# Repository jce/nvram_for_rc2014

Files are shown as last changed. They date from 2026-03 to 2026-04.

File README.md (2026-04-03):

## NVRAM module for the RC2014.
Pages the lower 32K out when the ROM module is present. Does not forget its content even when powered off. Therefore can be used as program storage in addition to remanent data.

Data and address traces are mostly connected in sequence. This means the ordering is slightly jumbled. But writing and reading back memory content makes the same transformations so this is functionally fine.

PCB 1.1 front
PCB 1.1 back
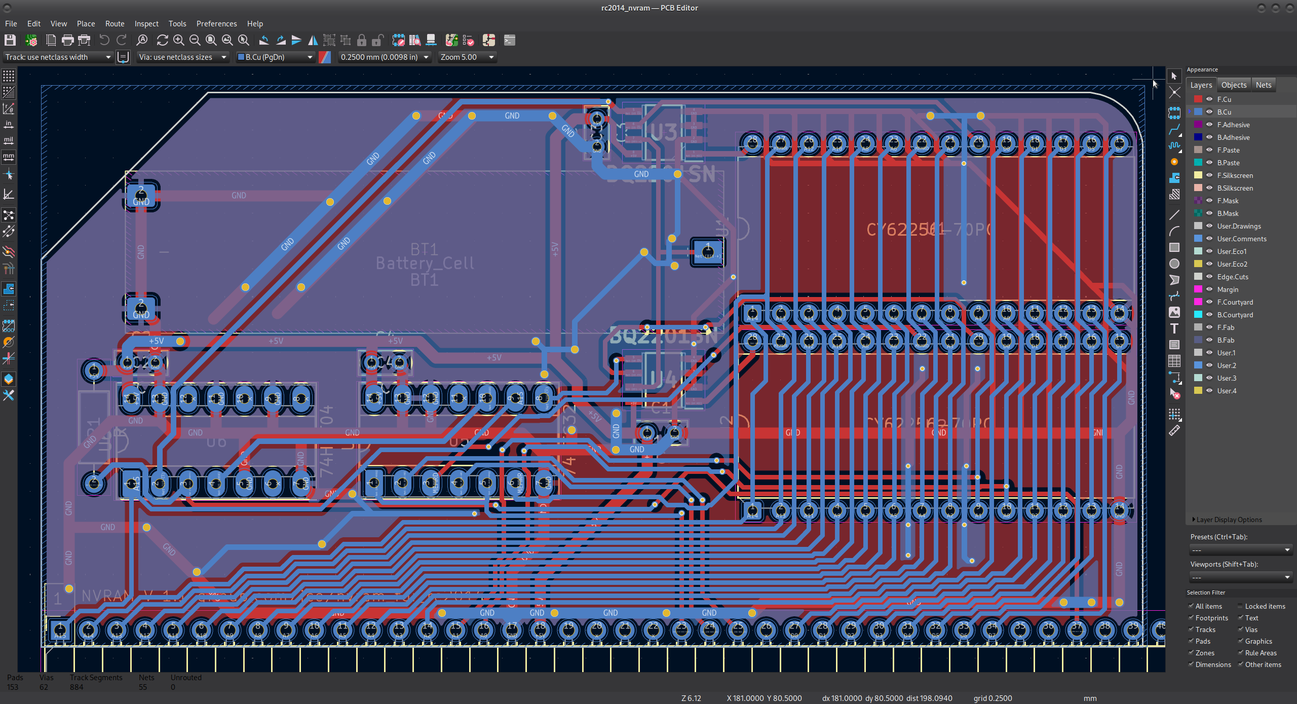
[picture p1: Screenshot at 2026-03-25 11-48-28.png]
PCB 1.1 kicad


Errata for building pcb V 1.1 (actual, and in picture):
- Typo in ic name: 74HTC32 should be 74HCT32
- Resistor and capacitor value not in drawing / on silkscreen
- Hole in RC2014 standard is missing
- "Page" pin is on SPARE1, instead of the second pinheader row, which is absent.

Errata for building of the V 1.0 proto:
- 74LS32 should be 74HTC32
- RC2014bus pin1 is not indicated
- IC types are not on silkscreen
- Pull up resistor value is missing: 10K
- Partlist missing
- Ground issues. Bridge some ground planes if you want to use this proto!
- Top memory is the bottom ic, ic's are reversed.

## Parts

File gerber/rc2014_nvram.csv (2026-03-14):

Id | Designator | Footprint | Quantity | Designation | Supplier and ref
1 | U5 | DIP-14_W7.62mm_Socket_LongPads | 1 | 74HTC32
2 | U1,U2 | DIP-28_W15.24mm | 2 | CY62256-70PC
3 | R1 | R_Axial_DIN0207_L6.3mm_D2.5mm_P10.16mm_Horizontal | 1 | 10K
4 | U6 | DIP-14_W7.62mm_Socket_LongPads | 1 | 74HCT04
5 | Z80_BUS1 | PinHeader_1x40_P2.54mm_Horizontal | 1 | ~
6 | BT1 | ER14505 | 1 | Battery_Cell
7 | C3,C1,C4,C2 | C_Rect_L4.6mm_W2.0mm_P2.50mm_MKS02_FKP02 | 4 | C
8 | U3,U4 | SOIC127P600X175-8N | 2 | BQ2201SN

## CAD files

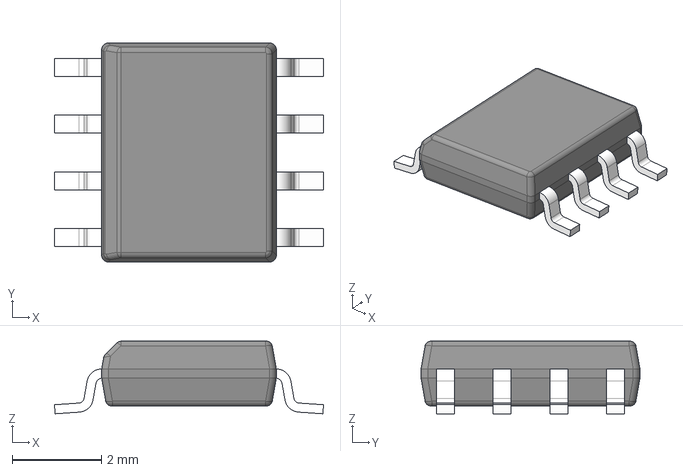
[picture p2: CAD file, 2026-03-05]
BQ2201SN-N/3D/BQ2201SN-N.stp
6.02 x 4.90 x 1.63 mm
BODY-SO
LEAD-D0008B x 8

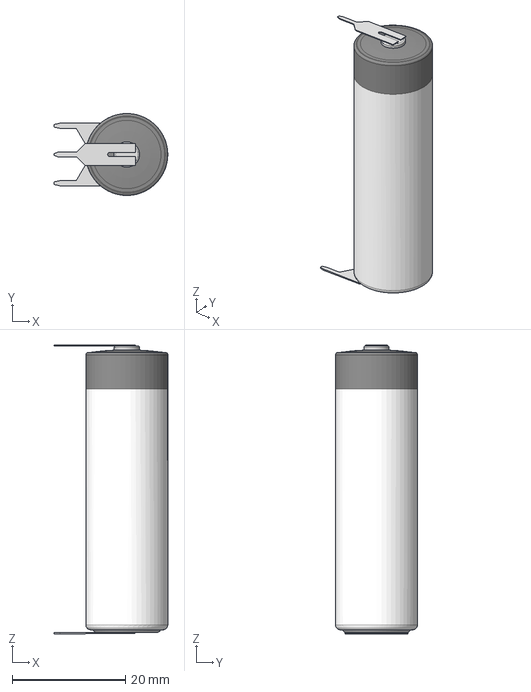
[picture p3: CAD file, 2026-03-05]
ER145053FP.stp
20.1 x 14.5 x 51.1 mm

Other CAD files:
BQ2201SN-N/Allegro/soic127p600x175-8n.psm
BQ2201SN-N/DEHDL/bq2201sn_n/chips/chips.prt

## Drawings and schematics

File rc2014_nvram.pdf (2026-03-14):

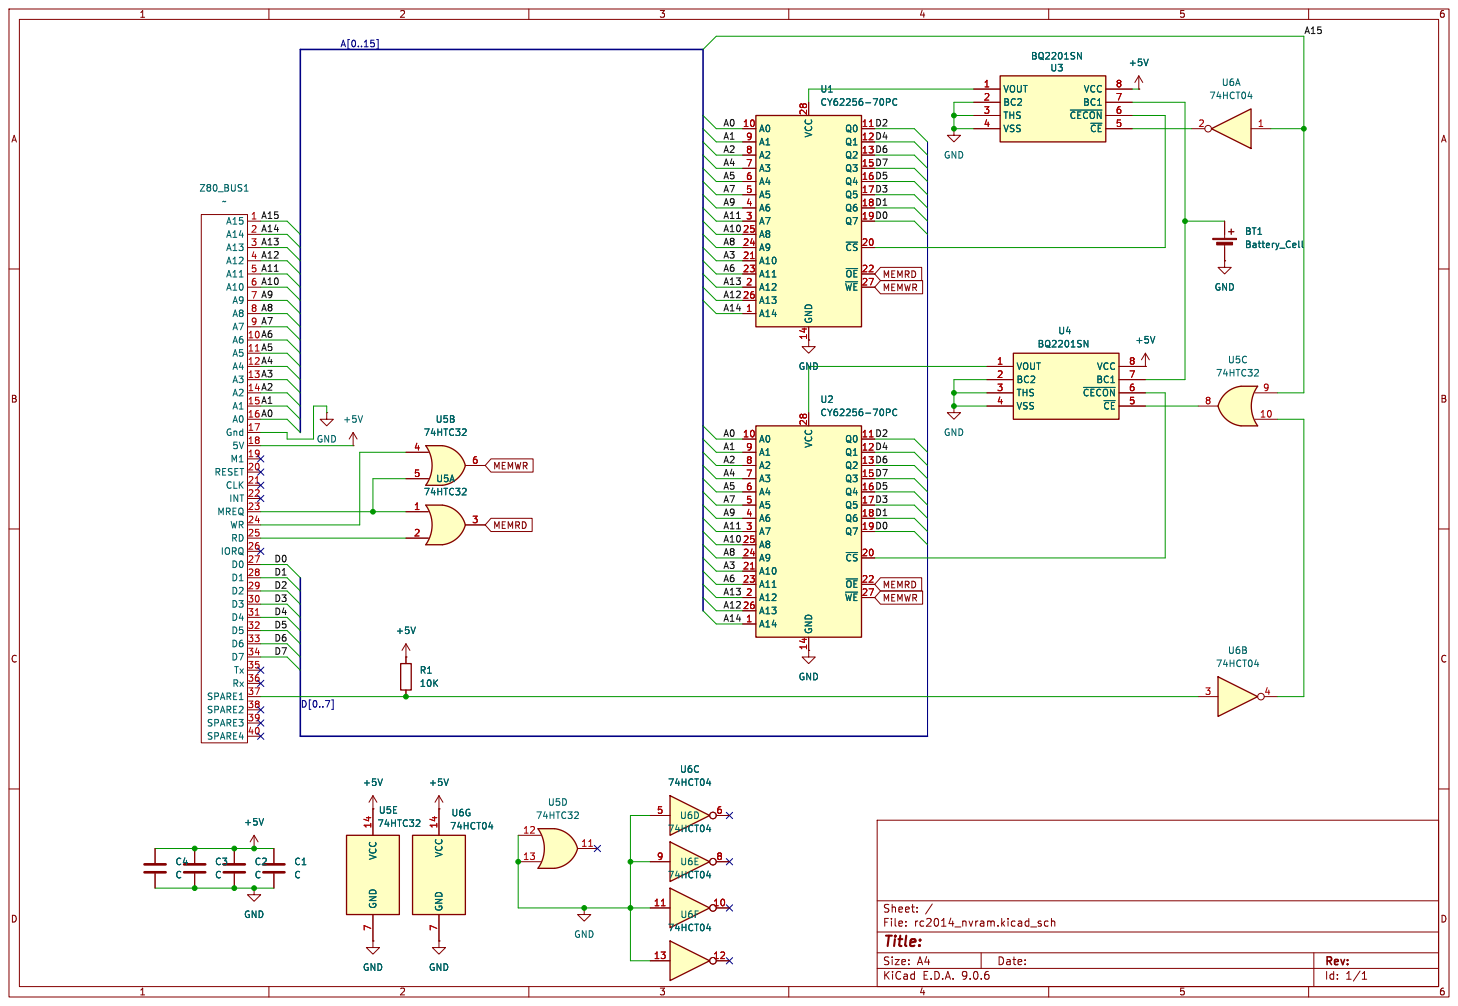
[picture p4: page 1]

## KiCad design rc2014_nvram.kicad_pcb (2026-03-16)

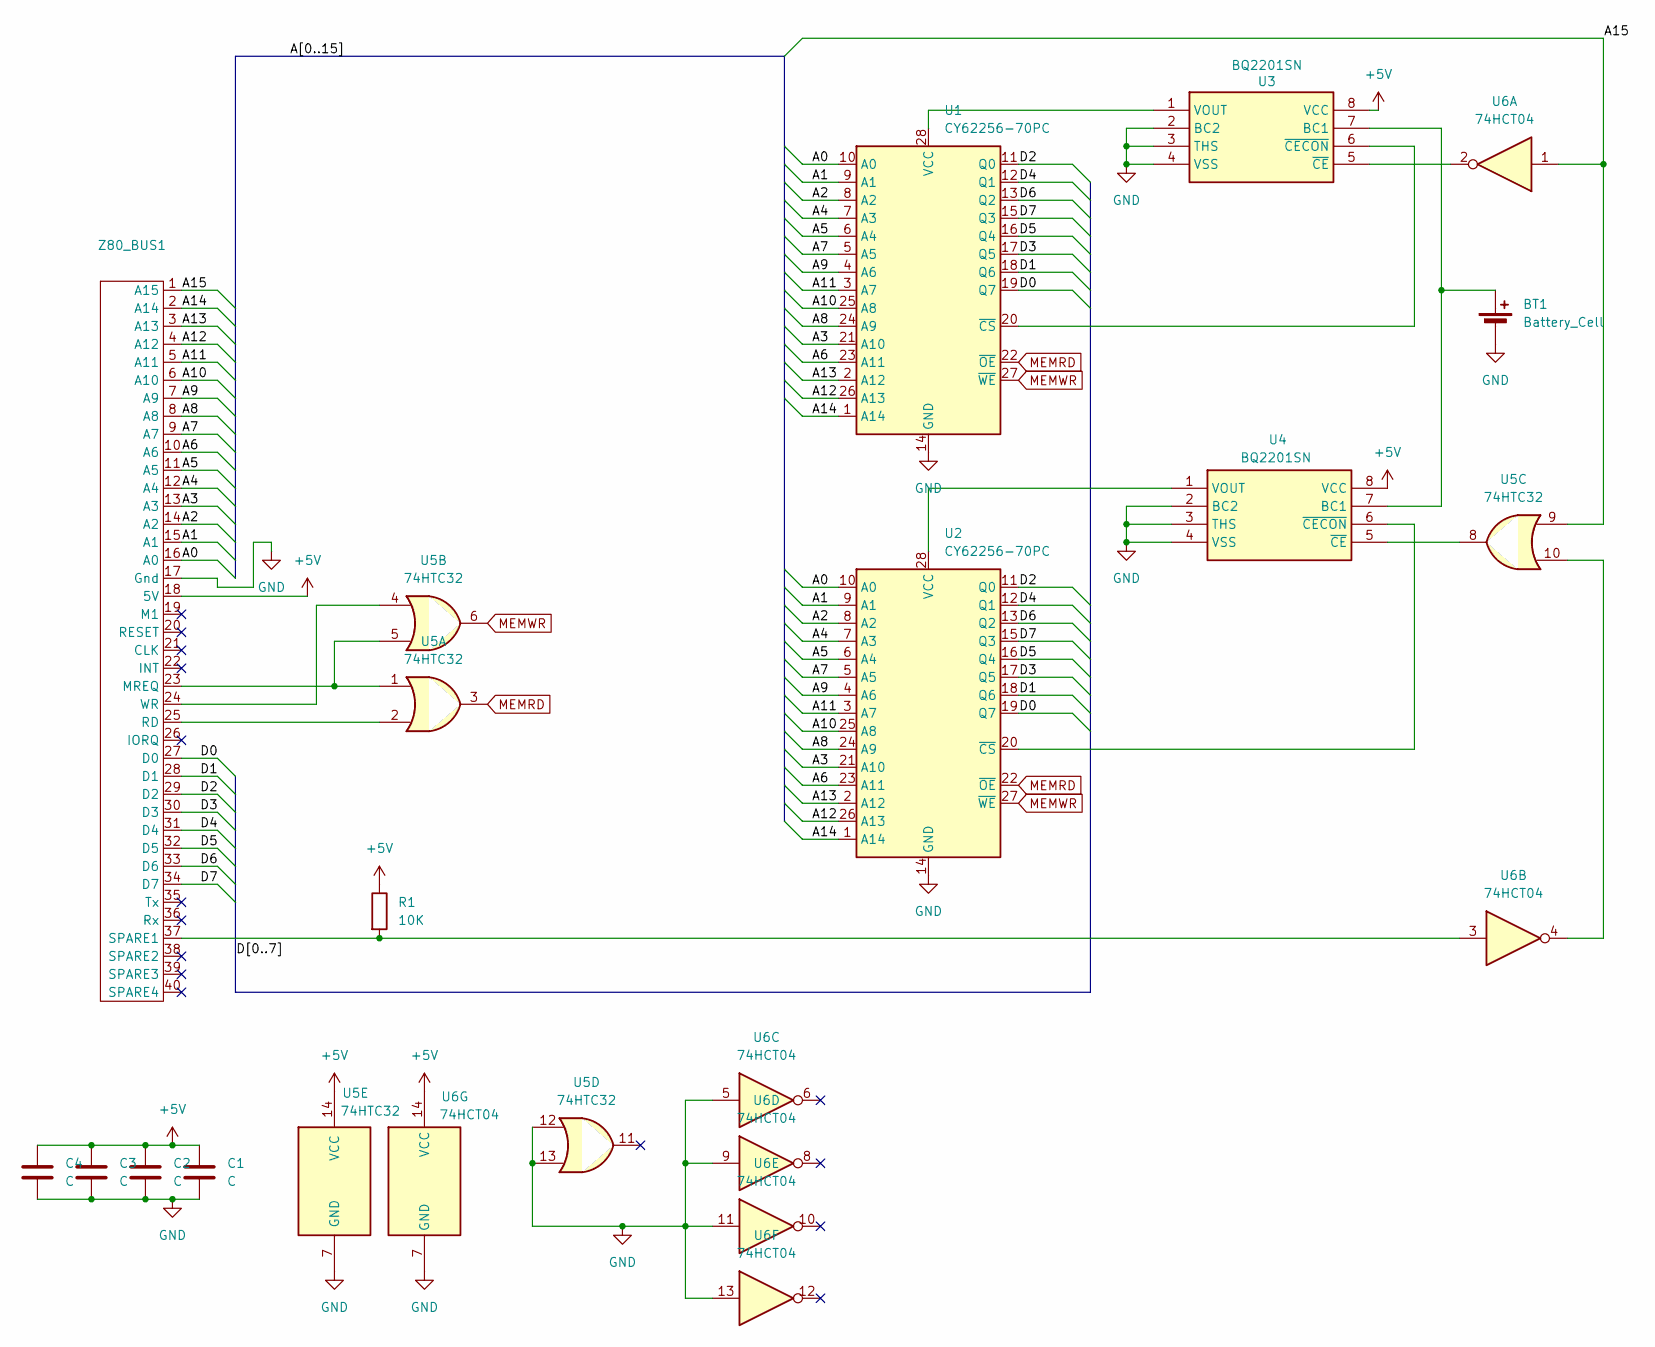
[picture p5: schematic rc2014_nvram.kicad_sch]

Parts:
BT1: Battery_Cell; ER14505
C1, C2, C3, C4: C; C_Rect_L4.6mm_W2.0mm_P2.50mm_MKS02_FKP02
R1: 10K; R_Axial_DIN0207_L6.3mm_D2.5mm_P10.16mm_Horizontal
U1, U2: CY62256-70PC; DIP-28_W15.24mm
U3, U4: BQ2201SN; SOIC127P600X175-8N; Mouser Part Number 595-BQ2201SN-N
U5: 74HTC32; DIP-14_W7.62mm_Socket_LongPads
U6: 74HCT04; DIP-14_W7.62mm_Socket_LongPads
Z80_BUS1: PinHeader_1x40_P2.54mm_Horizontal

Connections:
+5V: C1.1, C2.1, C3.1, C4.1, R1.1, U3.8 (VCC), U4.8 (VCC), U5.14 (VCC), U6.14 (VCC), Z80_BUS1.18 (5V)
/A0: U1.10 (A0), U2.10 (A0), Z80_BUS1.16 (A0)
/A1: U1.9 (A1), U2.9 (A1), Z80_BUS1.15 (A1)
/A2: U1.8 (A2), U2.8 (A2), Z80_BUS1.14 (A2)
/A3: U1.21 (A10), U2.21 (A10), Z80_BUS1.13 (A3)
/A4: U1.7 (A3), U2.7 (A3), Z80_BUS1.12 (A4)
/A5: U1.6 (A4), U2.6 (A4), Z80_BUS1.11 (A5)
/A6: U1.23 (A11), U2.23 (A11), Z80_BUS1.10 (A6)
/A7: U1.5 (A5), U2.5 (A5), Z80_BUS1.9 (A7)
/A8: U1.24 (A9), U2.24 (A9), Z80_BUS1.8 (A8)
/A9: U1.4 (A6), U2.4 (A6), Z80_BUS1.7 (A9)
/A10: U1.25 (A8), U2.25 (A8), Z80_BUS1.6 (A10)
/A11: U1.3 (A7), U2.3 (A7), Z80_BUS1.5 (A11)
/A12: U1.26 (A13), U2.26 (A13), Z80_BUS1.4 (A12)
/A13: U1.2 (A12), U2.2 (A12), Z80_BUS1.3 (A13)
/A14: U1.1 (A14), U2.1 (A14), Z80_BUS1.2 (A14)
/A15: U5.9, U6.1, Z80_BUS1.1 (A15)
/D0: U1.19 (Q7), U2.19 (Q7), Z80_BUS1.27 (D0)
/D1: U1.18 (Q6), U2.18 (Q6), Z80_BUS1.28 (D1)
/D2: U1.11 (Q0), U2.11 (Q0), Z80_BUS1.29 (D2)
/D3: U1.17 (Q5), U2.17 (Q5), Z80_BUS1.30 (D3)
/D4: U1.12 (Q1), U2.12 (Q1), Z80_BUS1.31 (D4)
/D5: U1.16 (Q4), U2.16 (Q4), Z80_BUS1.32 (D5)
/D6: U1.13 (Q2), U2.13 (Q2), Z80_BUS1.33 (D6)
/D7: U1.15 (Q3), U2.15 (Q3), Z80_BUS1.34 (D7)
GND: BT1.2 (-), C1.2, C2.2, C3.2, C4.2, U1.14 (GND), U2.14 (GND), U3.2 (BC2), U3.3 (THS), U3.4 (VSS), U4.2 (BC2), U4.3 (THS), U4.4 (VSS), U5.7 (GND), U5.12, U5.13, U6.5, U6.7 (GND), U6.9, U6.11, U6.13, Z80_BUS1.17 (Gnd)
MEMRD: U1.22 (~OE), U2.22 (~OE), U5.3
MEMWR: U1.27 (~WE), U2.27 (~WE), U5.6
unnamed: BT1.1 (+), U3.7 (BC1), U4.7 (BC1)
unnamed: U1.28 (VCC), U3.1 (VOUT)
unnamed: U1.20 (~CS), U3.6 (~CECON)
unnamed: U2.28 (VCC), U4.1 (VOUT)
unnamed: U2.20 (~CS), U4.6 (~CECON)
unnamed: U3.5 (~CE), U6.2
unnamed: U4.5 (~CE), U5.8
unnamed: U5.10, U6.4
unnamed: U5.1, U5.5, Z80_BUS1.23 (MREQ)
unnamed: U5.2, Z80_BUS1.25 (RD)
unnamed: R1.2, U6.3, Z80_BUS1.37 (SPARE1)
unnamed: U5.4, Z80_BUS1.24 (WR)

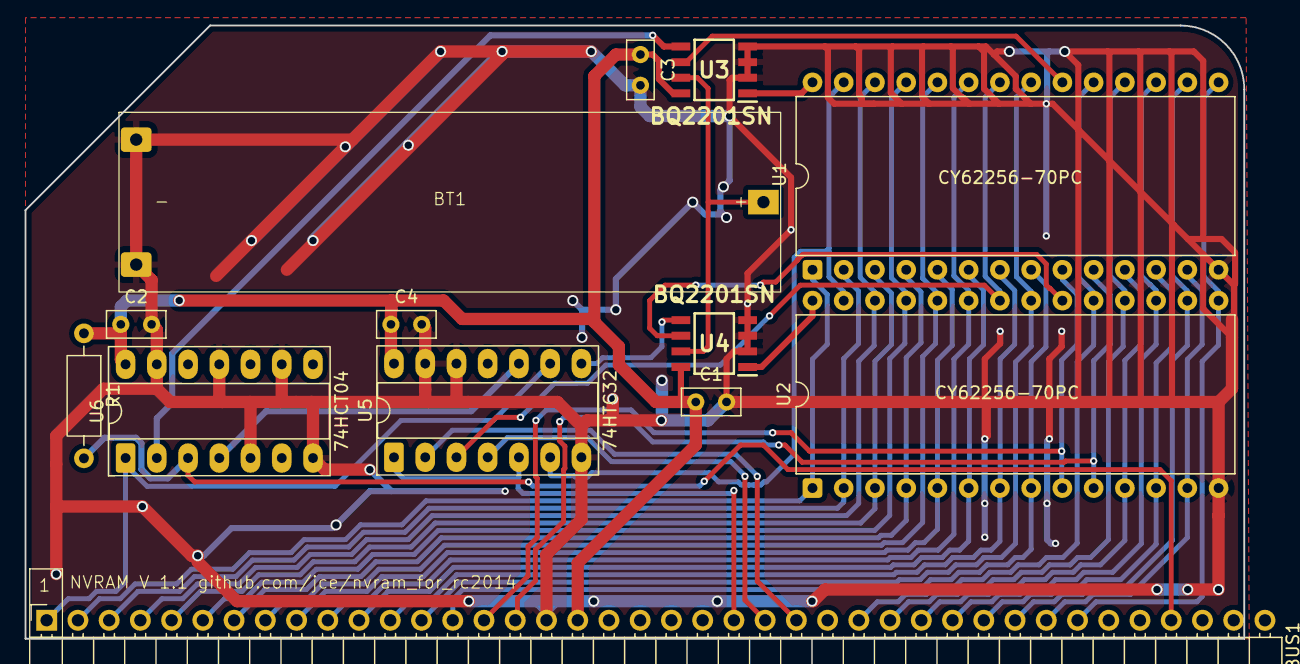
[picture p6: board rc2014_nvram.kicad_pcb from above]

Board: 2 copper layers, 99.1 x 49.9 mm, 13 parts (0 on the bottom side), 40 nets.

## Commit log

2026-03-05 V 1.0, first proto run
    [BQ2201SN-N.SchLib, BQ2201SN-N.stp, EDI2CAP.CFG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]
2026-03-08 added schematic pdf
2026-03-14 Fix grounding issues
    [rc2014_nvram-B_Cu.gbr, rc2014_nvram-B_Mask.gbr, rc2014_nvram-B_Paste.gbr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]
2026-03-16 V 1.1, second proto run
    [rc2014_nvram-B_Cu.gbr, rc2014_nvram-B_Mask.gbr, rc2014_nvram-B_Paste.gbr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]
